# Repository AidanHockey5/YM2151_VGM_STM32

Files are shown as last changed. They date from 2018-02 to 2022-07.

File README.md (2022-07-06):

# This project has been superseded by...
https://github.com/AidanHockey5/YM2151_Arcade_Classic_2

# YM2151 Arcade Classic

http://www.aidanlawrence.com/ym2151-arcade-classic-adlib-mini/

See this project in action here: https://youtu.be/VlT8aX9DRZw

This project is a hardware Video Game Music (VGM) player that uses a genuine YM2151 FM synthesizer chip. 
This project is driven by an STM32 "Blue Pill" board, chosen for it's ample speed, I/O, and best of all, price!

Included in this repository is the source code for the project, all of the schematic files, a Bill of Materials, and a completed 
Ki-CAD printed circuitboard /w Gerber files. Feel free to produce your own board!

PCB

# Information about the main sound chips and VGM

The YM2151 was a popular sound synthesizer for classic arcade systems as well as a few higher-end home computers in the late 80's and early 90's.
This project synthesizes music from .VGM files in real time on genuine hardware. There is no emulation here.

VGM stands for Video Game Music, and it is a 44.1KHz logging format that stores real soundchip register information. My player will parse these files and send the data to the appropriate chips. You can learn more about the VGM file format here: http://www.smspower.org/Music/VGMFileFormat

http://www.smspower.org/uploads/Music/vgmspec170.txt?sid=58da937e68300c059412b536d4db2ca0

# SD Card Information
This project is built for full-sized SD cards, but you may use adapters to fit your desired card. You must format your SD card to Fat32 in order for this device to work correctly. Your SD card must only contain uncompressed .vgm files. VGZ FILES WILL NOT WORK! You may download .vgz files and use [7zip](http://www.7-zip.org/download.html) to extract the uncompressed file out of them. Vgm files on the SD card do not need to have the .vgm extension. As long as they contain valid, uncompressed vgm data, they will be read by the program regardless of their name.
You can find VGM files by Googling "myGameName VGM," or by checking out sites like http://vgmrips.net/packs/

# Control Over Serial
You can use a serial connection to control playback features. The commands are as follows:

Command | Result
------------ | -------------
\+ | Next Track
\- | Previous Track
\* | Random Track
\/ | Toggle Shuffle Mode
\. | Toggle Song Looping
r: | Request song

A song request is formatted as follows: ```r:mySongFile.vgm```
Once a song request is sent through the serial console, an attempt will be made to open that song file. The file must exist on the SD card, and spelling/capitalization must be correct.
Need an easy-to-use serial console? [I've made one here.](https://github.com/AidanHockey5/OpenArduinoSerialConsole)

# Schematic
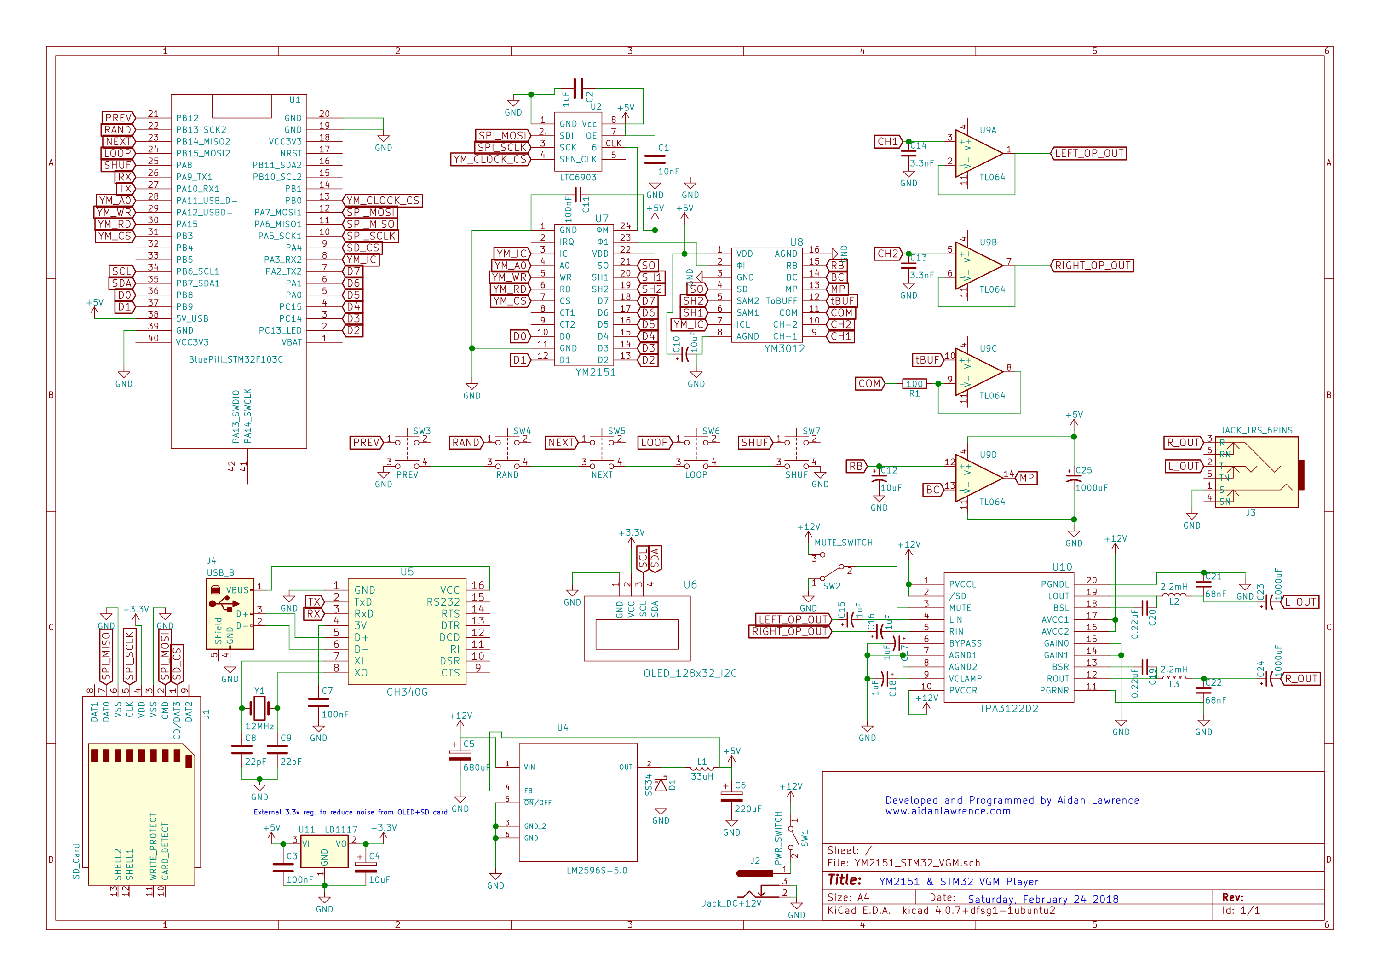
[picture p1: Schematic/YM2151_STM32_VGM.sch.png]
Schematic


[PDF](https://github.com/AidanHockey5/YM2151_VGM_STM32/raw/master/Schematic/YM2151_STM32_VGM.pdf)

[Bill Of Materials (BOM)](https://github.com/AidanHockey5/YM2151_VGM_STM32/tree/master/Schematic/BOM)

# KiCad
The schematic and PCB of this project was made in KiCad Version 4.0.7

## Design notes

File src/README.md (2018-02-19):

This project was a proof-of-concept to see if the STM32 could drive an FM synth chip.
There are no plans to support this project. For more detailed VGM players, see:
https://github.com/AidanHockey5/Teensy_3_5_VGM_Player_YM2612_SN76489
https://github.com/AidanHockey5/YM3812_VGM_Player

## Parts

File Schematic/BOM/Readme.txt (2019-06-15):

I've tried to keep as many components on Digikey as possible, but obviously, not everything will be on there.
That means that if you'd like a complete order of components, you must have all of the components from the DIGIKEY-BOM.csv file AND the EXTERNAL_BOM_ITEMS.txt list.

For items like resistors: Bog-standard 1/4 watt (the most common sizes you'd normally find in kits) will work, but I tried to track some down on Digikey any ways. 

For items listed on Aliexpress: Shop around and do your research. The links I provided should give you a great head start. Also check sources like eBay for similar goods.
LCSC can also provide parts at a significantly lower price than Digikey, but their selection is not as good. If you order a PCB from JLCPCB, you can ship components from LCSC combined for free.

You can use the Digikey BOM import tool to make this entire process much faster: https://www.digikey.com/BOM

Also, the 1000uF capacitors (C25, C24, C23) are actually have 2.5mm pin spacing, but Digikey only had 3.5mm spaced 8mm diameter caps. The fit isn't exactly perfect, but it's close enough to work.
If you can find 1000uF (16V or higher) capacitors that are 8mm in diameter and have 2.5mm pin spacing, I reccomend that you use those for a better fit.

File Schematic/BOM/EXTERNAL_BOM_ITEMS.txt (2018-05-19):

1x - J3 - AMP_OUT - PJ320E_3.5mm_Jack - https://www.aliexpress.com/wholesale?catId=0&initiative_id=SB_20180518120441&SearchText=PJ-320E
1x - U5 - CH340G - https://lcsc.com/product-detail/USB_CH340G_C14267.html 
1x - U1 - STM32 Bluepill Board - https://www.aliexpress.com/wholesale?catId=0&initiative_id=SB_20180518120532&SearchText=STM32F103C8T6
1x - U7 - YM2151 - https://www.aliexpress.com/wholesale?catId=0&initiative_id=SB_20180518182831&SearchText=YM2151
1x - U8 - YM3012 - https://www.aliexpress.com/w/wholesale-ym3012.html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
1x - U6 - 128x32 I2C OLED - https://www.aliexpress.com/wholesale?catId=0&initiative_id=SB_20180518182910&SearchText=128x32+I2C+OLED

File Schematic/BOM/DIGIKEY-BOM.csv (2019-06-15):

Manufacturer Part Number | Manufacturer | Digi-Key Part Number | Customer Reference | Reference Designator | Packaging | Part Status | Quantity | Unit Price | Extended Price | Quantity Available | Mfg Std Lead Time | Description | RoHS Status | Lead Free Status | REACH Status
ECS-120-20-4 | ECS Inc. | X227-ND |  |  | Bulk | Active | 1 | 0.69 | $0.69 | 1635 | 9 Weeks | CRYSTAL 12.0000MHZ 20PF T/H | RoHS non-compliant | Contains lead | REACH Unaffected
2041021-4 | TE Connectivity AMP Connectors | A101492CT-ND |  |  | Cut Tape (CT) | Active | 1 | 3.44 | $3.44 | 2777 | 11 Weeks | CONN SD CARD PUSH-PULL R/A SMD | RoHS Compliant | Lead free | Not Available
1825115-1 | TE Connectivity ALCOSWITCH Switches | 450-1598-ND |  |  | Bulk | Active | 2 | 0.98 | $1.96 | 3119 | 4 Weeks | SWITCH SLIDE SPDT 250MA 125V | RoHS Compliant | Lead free | Not Available
670688011 | Molex, LLC | WM12785-ND |  |  | Tube | Active | 1 | 2.06 | $2.06 | 1590 | 12 Weeks | USB B CONN WITH KINK BOARD LOCK | RoHS Compliant | Lead free | REACH Unaffected
16ZLH680MEFC10X12.5 | Rubycon | 1189-1150-ND |  |  | Bulk | Active | 1 | 0.43 | $0.43 | 6103 | 17 Weeks | CAP ALUM 680UF 20% 16V RADIAL | RoHS Compliant | Lead free | REACH Unaffected
LM2596S-5.0/NOPB | Texas Instruments | LM2596S-5.0/NOPB-ND |  |  | Tube | Active | 1 | 5.72 | $5.72 | 0 | 30 Weeks | IC REG BUCK 5V 3A TO263-5 | RoHS Compliant | Contains lead | REACH Unaffected
FG18X7R1H683KNT06 | TDK Corporation | 445-173278-1-ND |  |  | Cut Tape (CT) |  | 2 | 0.26 | $0.52 | 5414 | 40 Weeks | 0.068µF ±10% 50V Ceramic Capacitor X7R Radial | RoHS Compliant | Lead free | REACH Unaffected
PJ-002A | CUI Inc. | CP-002A-ND |  |  | Bag | Active | 1 | 0.6 | $0.60 | 113742 | Not Available | CONN PWR JACK 2X5.5MM SOLDER | RoHS Compliant | Lead free | Not Available
MBR0580S1-7 | Diodes Incorporated | MBR0580S1-7DICT-ND |  |  | Cut Tape (CT) | Active | 1 | 0.31 | $0.31 | 65469 | Not Available | DIODE SCHOTTKY 80V 500MA SOD123 | RoHS Compliant | Lead free | REACH Unaffected
K103K15X7RF5TL2 | Vishay BC Components | BC1078CT-ND |  |  | Cut Tape (CT) | Active | 1 | 0.19 | $0.19 | 9972 | 8 Weeks | CAP CER 10000PF 50V X7R RADIAL | RoHS Compliant | Lead free | Not Available
FG24X7R1H224KNT06 | TDK Corporation | 445-173377-1-ND |  |  | Cut Tape (CT) | Active | 2 | 0.29 | $0.58 | 4783 | 16 Weeks | CAP CER 0.22UF 50V X7R RADIAL | RoHS Compliant | Lead free | REACH Unaffected
LR1LJR10 | TE Connectivity Passive Product | A105964CT-ND |  |  | Cut Tape (CT) | Active | 1 | 0.39 | $0.39 | 12684 | 11 Weeks | RES 0.1 OHM 1/2W 5% AXIAL | RoHS Compliant | Lead free | Not Available
K104Z15Y5VF5TL2 | Vishay BC Components | BC1160CT-ND |  |  | Cut Tape (CT) | Active | 3 | 0.19 | $0.57 | 78547 | 8 Weeks | CAP CER 0.1UF 50V Y5V RADIAL | RoHS Compliant | Lead free | Not Available
UMA1C100MDD1TP | Nichicon | 493-10458-1-ND |  |  | Cut Tape (CT) | Active | 3 | 0.28 | $0.84 | 7221 | 21 Weeks | CAP ALUM 10UF 20% 16V RADIAL | RoHS Compliant | Lead free | REACH Unaffected
UMF1V010MDD1TP | Nichicon | 493-10230-1-ND |  |  | Cut Tape (CT) | Active | 4 | 0.45 | $1.80 | 2110 | 21 Weeks | CAP ALUM 1UF 20% 35V RADIAL | RoHS Compliant | Lead free | REACH Unaffected
FG28X7R1E105KRT06 | TDK Corporation | 445-173583-1-ND |  |  | Cut Tape (CT) | Active | 1 | 0.32 | $0.32 | 4648 | 16 Weeks | CAP CER 1UF 25V X7R RADIAL | RoHS Compliant | Lead free | REACH Unaffected
UVY1C221MED1TD | Nichicon | 493-12895-1-ND |  |  | Cut Tape (CT) | Active | 1 | 0.31 | $0.31 | 4437 | 18 Weeks | CAP ALUM 220UF 20% 16V RADIAL | RoHS Compliant | Lead free | REACH Unaffected
K220J15C0GF5TL2 | Vishay BC Components | BC1005CT-ND |  |  | Cut Tape (CT) | Active | 2 | 0.21 | $0.42 | 93566 | 8 Weeks | CAP CER 22PF 50V C0G/NP0 RADIAL | RoHS Compliant | Lead free | Not Available
K332K15X7RF5TL2 | Vishay BC Components | BC1075CT-ND |  |  | Cut Tape (CT) | Active | 2 | 0.2 | $0.40 | 42348 | 8 Weeks | CAP CER 3300PF 50V X7R RADIAL | RoHS Compliant | Lead free | Not Available
AIUR-16-330K | Abracon LLC | AIUR-16-330K-ND |  |  | Box | Active | 1 | 0.78 | $0.78 | 868 | 11 Weeks | FIXED IND 33UH 800MA 90 MOHM TH | RoHS Compliant | Lead free | REACH Unaffected
LTC6903CMS8#PBF | Linear Technology/Analog Devices | LTC6903CMS8#PBF-ND |  |  | Tube | Active | 1 | 4 | $4.00 | 311 | 8 Weeks | IC OSC SILICON PROG 8-MSOP | RoHS Compliant | Lead free | REACH Unaffected
B3F-1060 | Omron Electronics Inc-EMC Div | SW1177-ND |  |  | Bulk | Active | 5 | 0.34 | $1.70 | 2711 | 11 Weeks | SWITCH TACTILE SPST-NO 0.05A 24V | RoHS Compliant | Lead free | Not Available
TPA3122D2N | Texas Instruments | 296-23375-5-ND |  |  | Tube | Active | 1 | 3.31 | $3.31 | 421 | 6 Weeks | IC AMP AUDIO PWR 15W STER 20DIP | RoHS Compliant | Lead free | REACH Unaffected
A 20-LC-TT | Assmann WSW Components | AE9998-ND |  |  | Tube | Active | 1 | 0.29 | $0.29 | 44887 | 20 Weeks | CONN IC DIP SOCKET 20POS TIN | RoHS Compliant | Lead free | REACH Unaffected
A 24-LC-TT | Assmann WSW Components | AE10001-ND |  |  | Tube | Active | 1 | 0.35 | $0.35 | 6647 | 20 Weeks | CONN IC DIP SOCKET 24POS TIN | RoHS Compliant | Lead free | REACH Unaffected
A 16-LC-TT | Assmann WSW Components | AE9992-ND |  |  | Tube | Active | 1 | 0.25 | $0.25 | 44988 | 20 Weeks | CONN IC DIP SOCKET 16POS TIN | RoHS Compliant | Lead free | REACH Unaffected
A 14-LC-TT | Assmann WSW Components | AE9989-ND |  |  | Tube | Active | 1 | 0.22 | $0.44 | 121951 | 20 Weeks | CONN IC DIP SOCKET 14POS TIN | RoHS Compliant | Lead free | REACH Unaffected
TL064CN | Texas Instruments | 296-1773-5-ND |  |  | Tube | Active | 1 | 0.65 | $0.65 | 2461 | 6 Weeks | IC OPAMP JFET 1MHZ 14DIP | RoHS Compliant | Lead free | REACH Unaffected
RLB1014-222KL | Bourns Inc. | RLB1014-222KL-ND |  |  | Bag | Active | 2 | 0.43 | $0.86 | 1019 | 20 Weeks | FIXED IND 2.2MH 110MA 8.4 OHM TH | RoHS Compliant | Lead free | REACH Unaffected
UHV1C102MPD6 | Nichicon | 493-16434-ND |  |  | Bulk | Active | 3 | 0.65 | $1.95 | 677 | 20 Weeks | CAP ALUM 1000UF 20% 16V RADIAL | RoHS Compliant | Lead free | REACH Unaffected
LD1117S33CTR | STMicroelectronics | 497-1241-1-ND |  |  | Cut Tape (CT) | Active | 1 | 0.42 | $0.42 | 77479 | 10 Weeks | IC REG LINEAR 3.3V 800MA SOT223 | RoHS Compliant | Lead free | REACH Unaffected

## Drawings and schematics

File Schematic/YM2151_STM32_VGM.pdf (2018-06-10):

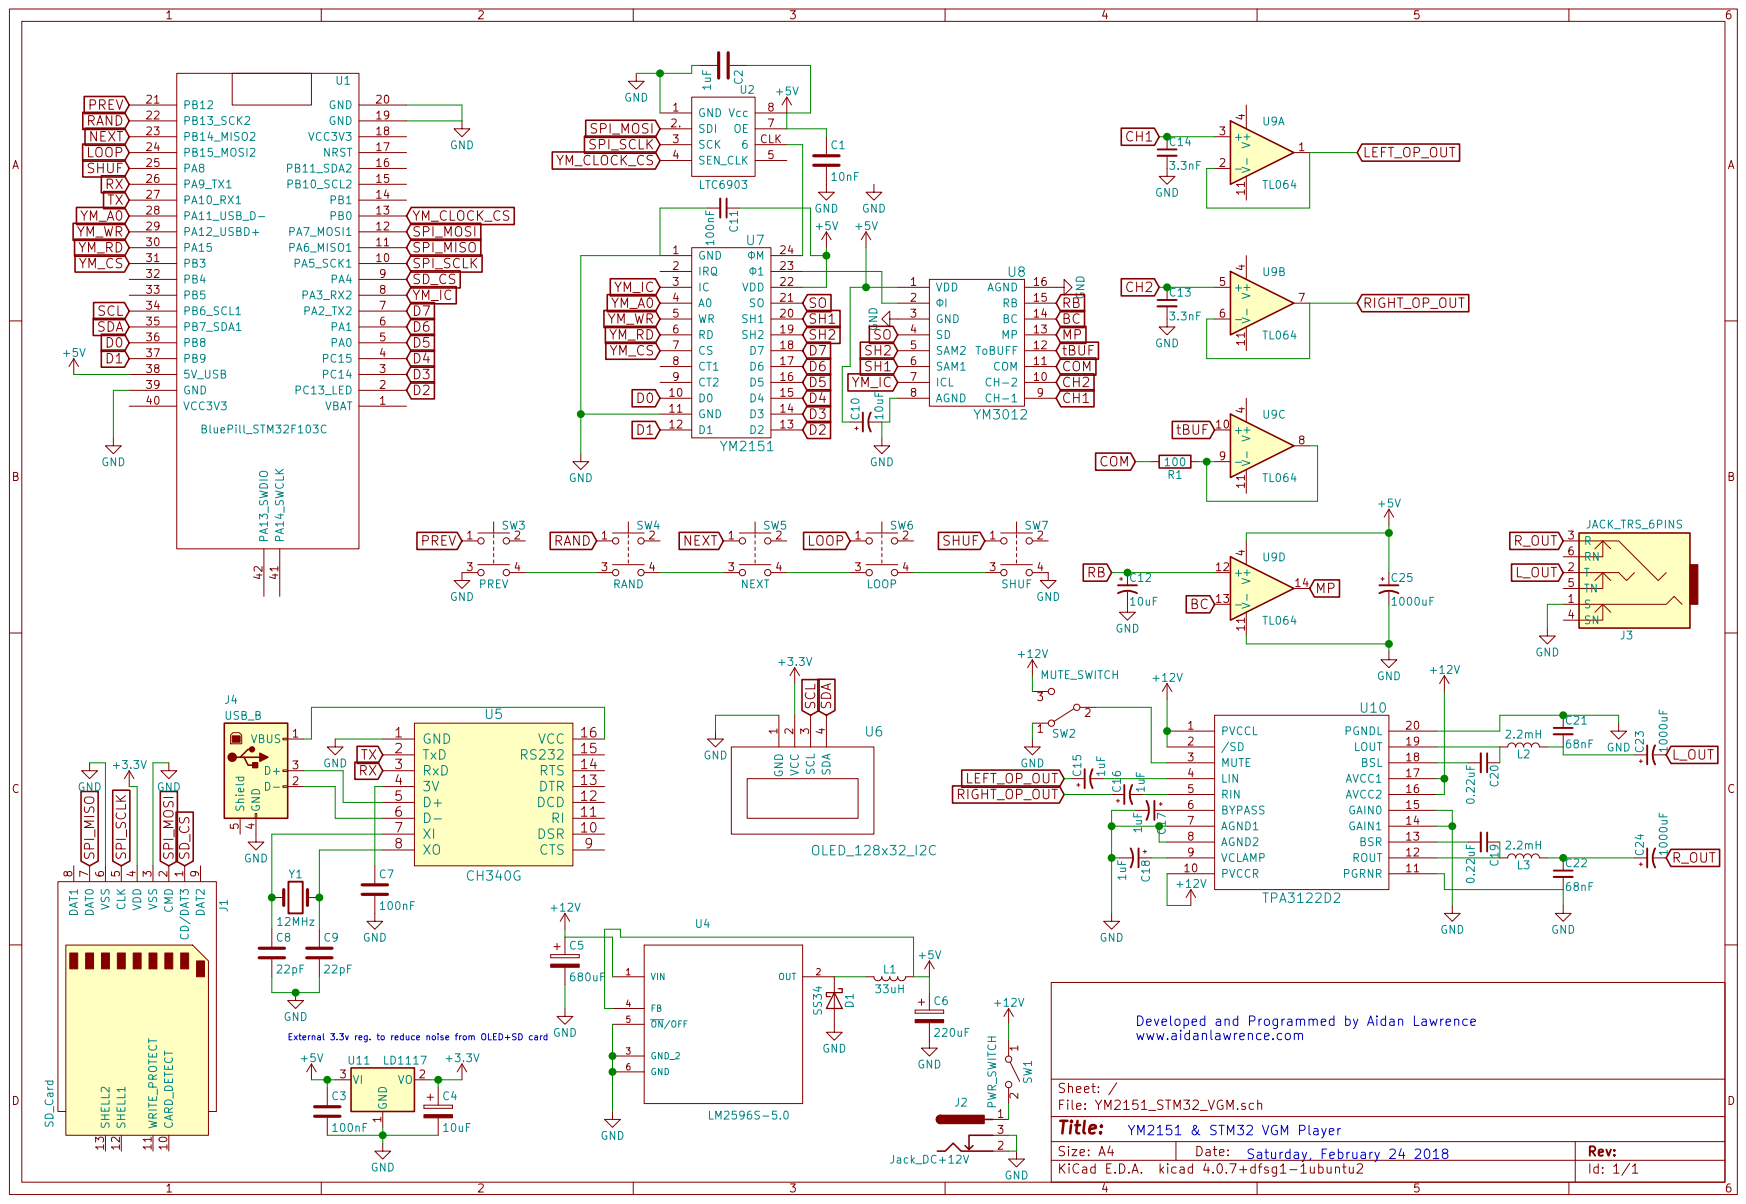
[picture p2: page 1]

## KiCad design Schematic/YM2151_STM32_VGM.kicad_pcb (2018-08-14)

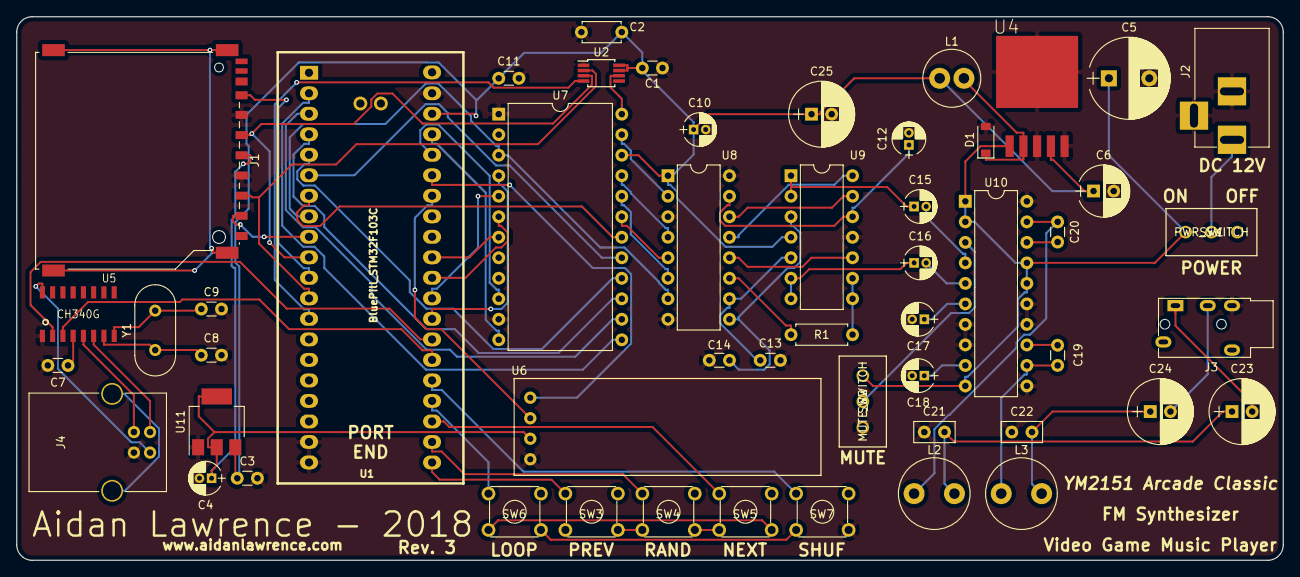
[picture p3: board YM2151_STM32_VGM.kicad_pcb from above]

Board: 2 copper layers, 156.8 x 67.3 mm, 52 parts (0 on the bottom side), 71 nets.

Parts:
C1: 10nF; C_Disc_D3.0mm_W1.6mm_P2.50mm
C2: 1uF; C_Disc_D4.7mm_W2.5mm_P5.00mm
C3, C7, C11: 100nF; C_Disc_D3.0mm_W1.6mm_P2.50mm
C4, C10, C12: 10uF; CP_Radial_D4.0mm_P1.50mm
C5: 680uF; CP_Radial_D10.0mm_P5.00mm
C6: 220uF; CP_Radial_D6.3mm_P2.50mm
C8, C9: 22pF; C_Disc_D3.0mm_W1.6mm_P2.50mm
C13, C14: 3.3nF; C_Disc_D3.0mm_W1.6mm_P2.50mm
C15, C16, C17, C18: 1uF; CP_Radial_D4.0mm_P1.50mm
C19, C20: 0.22uF; C_Disc_D3.0mm_W1.6mm_P2.50mm
C21, C22: 68nF; C_Disc_D5.0mm_W2.5mm_P2.50mm
C23, C24, C25: 1000uF; CP_Radial_D8.0mm_P2.50mm
D1: SS34; D_SOD-123
J1: SD_Card; SD_TE_2041021
J2: Jack_DC+12V; BARREL_JACK
J3: JACK_TRS_6PINS; PJ320E_3.5mm_Jack
J4: USB_B
L1: 33uH; L_Radial_D7.0mm_P3.00mm
L2, L3: 22uH; L_Radial_D8.7mm_P5.00mm_Fastron_07HCP
R1: 100; R_Axial_DIN0207_L6.3mm_D2.5mm_P7.62mm_Horizontal
SW1: PWR_SWITCH; 1825115-1
SW2: MUTE_SWITCH; 1825115-1
SW3: PREV; SW_TH_Tactile_Omron_B3F-10xx
SW4: RAND; SW_TH_Tactile_Omron_B3F-10xx
SW5: NEXT; SW_TH_Tactile_Omron_B3F-10xx
SW6: LOOP; SW_TH_Tactile_Omron_B3F-10xx
SW7: SHUF; SW_TH_Tactile_Omron_B3F-10xx
U1: BluePill_STM32F103C
U2: LTC6903; MSOP-8_3x3mm_Pitch0.65mm
U4: LM2596S-5.0; TO170P1435X465-6N
U5: CH340G; SOIC16
U6: OLED_128x32_I2C; 128x32_OLED_I2C_Module
U7: YM2151; DIP-24_W15.24mm
U8: YM3012; DIP-16_W7.62mm
U9: TL064; DIP-14_W7.62mm
U10: TPA3122D2; DIP-20_W7.62mm
U11: LD1117; SOT-223-3_TabPin2
Y1: 12MHz; Crystal_HC49-U_Vertical

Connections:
+3V3: C4.1, J1.4, U6.2, U11.2
+5V: C1.1, C2.1, C3.1, C6.1, C10.1, C11.1, C25.1, L1.1, U1.38, U2.7, U2.8, U4.4, U7.22, U8.1, U9.4, U11.3
+12V: C5.1, SW1.1, SW2.3, U4.1, U10.1, U10.2, U10.10, U10.16, U10.17
BC: U8.14, U9.13
CH1: C14.1, U8.9, U9.3
CH2: C13.1, U8.10, U9.5
COM: R1.2, U8.11
D0: U1.36, U7.10
D1: U1.37, U7.12
D2: U1.2, U7.13
D3: U1.3, U7.14
D4: U1.4, U7.15
D5: U1.5, U7.16
D6: U1.6, U7.17
D7: U1.7, U7.18
GND: C1.2, C2.2, C3.2, C4.2, C5.2, C6.2, C7.2, C8.2, C9.2, C10.2, C11.2, C12.2, C13.2, C14.2, C17.2, C18.2, C21.1, C22.2, C25.2, D1.2, J1.3, J1.6, J2.2, J2.3, J3.3, J4.4, SW2.1, SW3.3, SW7.4, U1.19, U1.20, U1.39, U2.1, U4.3, U4.5, U4.6, U5.1, U6.1, U7.1, U7.11, U8.3, U8.8, U8.16, U9.11, U10.7, U10.8, U10.11, U10.14, U10.15, U10.20, U11.1
LEFT_OP_OUT: C15.1, U9.1, U9.2
LOOP: SW6.1, U1.24
L_OUT: C23.2, J3.1
MP: U8.13, U9.14
NEXT: SW5.1, U1.23
unnamed: C7.1, U5.4
unnamed: C8.1, U5.7, Y1.1
unnamed: C9.1, U5.8, Y1.2
unnamed: C15.2, U10.4
unnamed: C16.2, U10.5
unnamed: C17.1, U10.6
unnamed: C18.1, U10.9
unnamed: C19.1, L3.1, U10.12
unnamed: C19.2, U10.13
unnamed: C20.1, L2.1, U10.19
unnamed: C20.2, U10.18
unnamed: C21.2, C23.1, L2.2
unnamed: C22.1, C24.1, L3.2
unnamed: D1.1, L1.2, U4.2
unnamed: J2.1, SW1.2
unnamed: J4.1, U5.16
unnamed: J4.2, U5.6
unnamed: J4.3, U5.5
unnamed: R1.1, U9.8, U9.9
unnamed: SW2.2, U10.3
unnamed: SW3.4, SW4.3
unnamed: SW4.4, SW5.3
unnamed: SW5.4, SW6.3
unnamed: SW6.4, SW7.3
unnamed: U2.6, U7.24
unnamed: U7.23, U8.2
PREV: SW3.1, U1.21
RAND: SW4.1, U1.22
RB: C12.1, U8.15, U9.12
RIGHT_OP_OUT: C16.1, U9.6, U9.7
RX: U1.26, U5.3
R_OUT: C24.2, J3.2
SCL: U1.34, U6.3
SDA: U1.35, U6.4
SD_CS: J1.1, U1.9
SH1: U7.20, U8.6
SH2: U7.19, U8.5
SHUF: SW7.1, U1.25
SO: U7.21, U8.4
SPI_MISO: J1.7, U1.11
SPI_MOSI: J1.2, U1.12, U2.2
SPI_SCLK: J1.5, U1.10, U2.3
TX: U1.27, U5.2
YM_A0: U1.28, U7.4
YM_CLOCK_CS: U1.13, U2.4
YM_CS: U1.31, U7.7
YM_IC: U1.8, U7.3, U8.7
YM_RD: U1.30, U7.6
YM_WR: U1.29, U7.5
tBUF: U8.12, U9.10

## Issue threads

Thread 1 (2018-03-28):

Error opening schematic in KiCad

SteveMoody73, 2018-03-28:
It looks like you're missing some library files. When opening the schematic in KiCad i get the following errors.

**The following libraries were not found:**

C:\Users\Aidan\Documents\KiCad_Custom_Libs\bluepill_breakouts
C:\Users\Aidan\Documents\Arduino\Teensy_3_5_VGM_Player_YM2612_SN76489\SchematicsAndInfo\Teensy_3_5_VGM_Player-cache
C:\Users\Aidan\Documents\KiCad_Custom_Libs\LM2596S-5.0
C:\Users\Aidan\Documents\KiCad_Custom_Libs\CH340G_D-SUN-V3.0-cache
C:\Users\Aidan\Documents\KiCad_Custom_Libs\VGM_Components_Library
C:\Users\Aidan\Documents\KiCad_Custom_Libs\TPA3122D2
C:\Users\Aidan\Documents\KiCad_Custom_Libs\DM3CS-SF
C:\Users\Aidan\Documents\KiCad_Custom_Libs\1825115Swit

AidanHockey5, 2018-03-31:
Sorry about that. I'm still getting over KiCAD's miserable library system. All footprints/symbols should now be locally stored within the project folder and referenced relative to the project's location.

Closed 2018-03-31.

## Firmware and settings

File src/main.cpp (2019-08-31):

#include <Arduino.h>
#include "YM2151.h"
#include "LTC6903.h"
#include <SPI.h>
#include <U8g2lib.h>
#include "SdFat.h"
#include "TrackStructs.h"
#include "ringbuffer.h"

//Debug variables
#define DEBUG false //Set this to true for a detailed printout of the header data & any errored command bytes
#define DEBUG_LED PA10
bool commandFailed = false;
uint8_t failedCmd = 0x00;

//Prototypes
void setup();
void loop();
void handleSerialIn();
void tick();
void removeMeta();
void prebufferLoop();
void injectPrebuffer();
void fillBuffer();
bool topUpBuffer(); 
void clearBuffers();
//void handleButtons();
void prepareChips();
void readGD3();
void setISR();
void drawOLEDTrackInfo();
bool startTrack(FileStrategy fileStrategy, String request = "");
bool vgmVerify();
uint8_t readBuffer();
uint16_t readBuffer16();
uint32_t readBuffer32();
uint32_t readSD32();
uint16_t parseVGM();

//Sound Chips
const int prev_btn = PB12;
const int rand_btn = PB13;
const int next_btn = PB14;
const int loop_btn = PB15;
const int shuf_btn = PA8;
int YM_Datapins[8] = {PB8, PB9, PC13, PC14, PC15, PA0, PA1, PA2};
const int YM_CS = PB3;
const int YM_RD = PA15;
const int YM_WR = PA12;
const int YM_A0 = PA11;
const int YM_IC = PA3; 
const int YM_IRQ = NULL;
YM2151 opm(YM_Datapins, YM_CS, YM_RD, YM_WR, YM_A0, YM_IRQ, YM_IC);

//Clock
LTC6903 ltc(PB0);

//SD & File Streaming
SdFat SD;
File file;
#define MAX_FILE_NAME_SIZE 128
char fileName[MAX_FILE_NAME_SIZE];
uint32_t numberOfFiles = 0;
uint32_t currentFileNumber = 0;

//Buffers
#define CMD_BUFFER_SIZE 8192
#define LOOP_PREBUF_SIZE 512
typedef ringbuffer_t<uint8_t, CMD_BUFFER_SIZE, uint8_t> RingBuffer;
static RingBuffer cmdBuffer;
uint8_t loopPreBuffer[LOOP_PREBUF_SIZE];

//Counters
uint32_t bufferPos = 0;
uint32_t cmdPos = 0;
uint16_t waitSamples = 0;

//VGM Variables
uint16_t loopCount = 0;
uint8_t maxLoops = 3;
bool fetching = false;
volatile bool ready = false;
PlayMode playMode = SHUFFLE;

//OLED
U8G2_SSD1306_128X32_UNIVISION_F_HW_I2C u8g2(U8G2_R0);

void setup()
{
  ltc.SetFrequency(3579545); 
  u8g2.begin();
  u8g2.setFont(u8g2_font_fub11_tf);
  u8g2.clearBuffer();
  u8g2.drawStr(0,16,"Aidan Lawrence");
  u8g2.drawStr(0,32,"YM2151, 2018");
  u8g2.sendBuffer();
  delay(500);
  pinMode(prev_btn, INPUT_PULLUP);
  pinMode(rand_btn, INPUT_PULLUP);
  pinMode(next_btn, INPUT_PULLUP);
  pinMode(loop_btn, INPUT_PULLUP);
  pinMode(shuf_btn, INPUT_PULLUP);

  //COM
  Serial.begin(9600);

  //SD
  if(!SD.begin(PA4, SD_SCK_HZ(F_CPU/2)))
  {
    u8g2.clearBuffer();
    u8g2.drawStr(0,16,"SD Mount");
    u8g2.drawStr(0,32,"failed!");
    u8g2.sendBuffer();
    while(true){Serial.println("SD MOUNT FAILED"); delay(1000);}
  }

  //Prepare files
  removeMeta();

  File countFile;
  while ( countFile.openNext( SD.vwd(), O_READ ))
  {
    countFile.close();
    numberOfFiles++;
  }
  countFile.close();
  SD.vwd()->rewind();

  //44.1KHz tick
  setISR();

  //Begin
  startTrack(FIRST_START);
  vgmVerify();
  prepareChips();
}

void setISR()
{
  Timer4.pause();
  Timer4.setPrescaleFactor(1);
  Timer4.setOverflow(1633);
  Timer4.setChannel1Mode(TIMER_OUTPUT_COMPARE);
  Timer4.attachCompare1Interrupt(tick);
  Timer4.refresh();
  Timer4.resume();  
}

void prepareChips()
{
  opm.Reset();
}

void drawOLEDTrackInfo()
{
  u8g2.setFont(u8g2_font_helvR08_tf);
  u8g2.clearBuffer();
  char *cstr = &gd3.enTrackName[0u];
  u8g2.drawStr(0,9, cstr);
  cstr = &gd3.enGameName[0u];
  u8g2.drawStr(0,22, cstr);

  u8g2.setFont(u8g2_font_micro_tr);
  if(playMode == LOOP)
    u8g2.drawStr(0,32, "LOOP");
  else if(playMode == SHUFFLE)
    u8g2.drawStr(0,32, "SHUFFLE");
  else
    u8g2.drawStr(0,32, "IN ORDER");
  u8g2.sendBuffer();
}

//Mount file and prepare for playback. Returns true if file is found.
bool startTrack(FileStrategy fileStrategy, String request)
{
  ready = false;
  File nextFile;
  memset(fileName, 0x00, MAX_FILE_NAME_SIZE);

  switch(fileStrategy)
  {
    case FIRST_START:
    {
      nextFile.openNext(SD.vwd(), O_READ);
      nextFile.getName(fileName, MAX_FILE_NAME_SIZE);
      nextFile.close();
      currentFileNumber = 0;
    }
    break;
    case NEXT:
    {
      if(currentFileNumber+1 >= numberOfFiles)
      {
          SD.vwd()->rewind();
          currentFileNumber = 0;
      }
      else
          currentFileNumber++;
      nextFile.openNext(SD.vwd(), O_READ);
      nextFile.getName(fileName, MAX_FILE_NAME_SIZE);
      nextFile.close();
    }
    break;
    case PREV:
    {
      if(currentFileNumber != 0)
      {
        currentFileNumber--;
        SD.vwd()->rewind();
        for(uint32_t i = 0; i<=currentFileNumber; i++)
        {
          nextFile.close();
          nextFile.openNext(SD.vwd(), O_READ);
        }
        nextFile.getName(fileName, MAX_FILE_NAME_SIZE);
        nextFile.close();
      }
      else
      {
        currentFileNumber = numberOfFiles-1;
        SD.vwd()->rewind();
        for(uint32_t i = 0; i<=currentFileNumber; i++)
        {
          nextFile.close();
          nextFile.openNext(SD.vwd(), O_READ);
        }
        nextFile.getName(fileName, MAX_FILE_NAME_SIZE);
        nextFile.close();
      }
    }
    break;
    case RND:
    {
      randomSeed(micros());
      uint32_t randomFile = currentFileNumber;
      if(numberOfFiles > 1)
      {
        while(randomFile == currentFileNumber)
          randomFile = random(numberOfFiles-1);
      }
      currentFileNumber = randomFile;
      SD.vwd()->rewind();
      nextFile.openNext(SD.vwd(), O_READ);
      {
        for(uint32_t i = 0; i<randomFile; i++)
        {
          nextFile.close();
          nextFile.openNext(SD.vwd(), O_READ);
        }
      }
      nextFile.getName(fileName, MAX_FILE_NAME_SIZE);
      nextFile.close();
    }
    break;
    case REQUEST:
    {
      SD.vwd()->rewind();
      bool fileFound = false;
      Serial.print("REQUEST: ");Serial.println(request);
      for(uint32_t i = 0; i<numberOfFiles; i++)
      {
        nextFile.close();
        nextFile.openNext(SD.vwd(), O_READ);
        nextFile.getName(fileName, MAX_FILE_NAME_SIZE);
        String tmpFN = String(fileName);
        tmpFN.trim();
        request.trim();
        if(tmpFN == request)
        {
          currentFileNumber = i;
          fileFound = true;
          break;
        }
      }
      nextFile.close();
      if(fileFound)
      {
        Serial.println("File found!");
      }
      else
      {
        Serial.println("ERROR: File not found! Continuing with current song.");
        ready = true;
        return false;
      }
    }
    break;
  }

  cmdPos = 0;
  bufferPos = 0;
  waitSamples = 0;
  loopCount = 0;

  if(file.isOpen())
    file.close();
  file = SD.open(fileName, FILE_READ);
  if(!file)
    Serial.println("Failed to read file");

  clearBuffers();
  memset(&loopPreBuffer, 0, LOOP_PREBUF_SIZE);
  header.Reset();
  fillBuffer();

  //VGM Header
  header.indent = readBuffer32();
  header.EoF = readBuffer32(); 
  header.version = readBuffer32(); 
  header.sn76489Clock = readBuffer32(); 
  header.ym2413Clock = readBuffer32();
  header.gd3Offset = readBuffer32();
  header.totalSamples = readBuffer32(); 
  header.loopOffset = readBuffer32(); 
  header.loopNumSamples = readBuffer32(); 
  header.rate = readBuffer32(); 
  header.snX = readBuffer32(); 
  header.ym2612Clock = readBuffer32(); 
  header.ym2151Clock = readBuffer32(); 
  header.vgmDataOffset = readBuffer32(); 
  header.segaPCMClock = readBuffer32(); 
  header.spcmInterface = readBuffer32(); 
  header.rf5C68clock = readBuffer32();
  header.ym2203clock = readBuffer32();
  header.ym2608clock = readBuffer32();
  header.ym2610clock = readBuffer32();
  header.ym3812clock = readBuffer32();
  header.ym3526clock = readBuffer32();
  header.y8950clock = readBuffer32();
  header.ymf262clock = readBuffer32();
  header.ymf271clock = readBuffer32();
  header.ymz280Bclock = readBuffer32();
  header.rf5C164clock = readBuffer32();
  header.pwmclock = readBuffer32();
  header.ay8910clock = readBuffer32();
  header.ayclockflags = readBuffer32();
  header.vmlblm = readBuffer32();
  if(header.version > 0x151)
  {
    header.gbdgmclock = readBuffer32();
    header.nesapuclock = readBuffer32();
    header.multipcmclock = readBuffer32();
    header.upd7759clock = readBuffer32();
    header.okim6258clock = readBuffer32();
    header.ofkfcf = readBuffer32();
    header.okim6295clock = readBuffer32();
    header.k051649clock = readBuffer32();
    header.k054539clock = readBuffer32();
    header.huc6280clock = readBuffer32();
    header.c140clock = readBuffer32();
    header.k053260clock = readBuffer32();
    header.pokeyclock = readBuffer32();
    header.qsoundclock = readBuffer32();
    header.scspclock = readBuffer32();
    header.extrahdrofs = readBuffer32();
    header.wonderswanclock = readBuffer32();
    header.vsuClock = readBuffer32();
    header.saa1099clock = readBuffer32();
  }

  #if DEBUG
  Serial.print("Indent: 0x"); Serial.println(header.indent, HEX);
  Serial.print("EoF: 0x"); Serial.println(header.EoF, HEX);
  Serial.print("Version: 0x"); Serial.println(header.version, HEX);
  Serial.print("SN Clock: "); Serial.println(header.sn76489Clock);
  Serial.print("YM2413 Clock: "); Serial.println(header.ym2413Clock);
  Serial.print("GD3 Offset: 0x"); Serial.println(header.gd3Offset, HEX);
  Serial.print("Total Samples: "); Serial.println(header.totalSamples);
  Serial.print("Loop Offset: 0x"); Serial.println(header.loopOffset, HEX);
  Serial.print("Loop # Samples: "); Serial.println(header.loopNumSamples);
  Serial.print("Rate: "); Serial.println(header.rate);
  Serial.print("SN etc.: 0x"); Serial.println(header.snX, HEX);
  Serial.print("YM2612 Clock: "); Serial.println(header.ym2612Clock);
  Serial.print("YM2151 Clock: "); Serial.println(header.ym2151Clock);
  Serial.print("VGM data Offset: 0x"); Serial.println(header.vgmDataOffset, HEX);
  Serial.print("SPCM Interface: 0x"); Serial.println(header.spcmInterface, HEX);
  Serial.println("...");
  Serial.print("YM3812 Clock: 0x"); Serial.println(header.ym3812clock, HEX);
  Serial.print("YMF262clock Clock: 0x"); Serial.println(header.ymf262clock, HEX);
  Serial.print("SAA1099 Clock: 0x"); Serial.println(header.saa1099clock, HEX);
  #endif

  //Jump to VGM data start and compute loop location
  if(header.vgmDataOffset == 0x0C)
    header.vgmDataOffset = 0x40;
  else
    header.vgmDataOffset += 0x34;
  
  if(header.vgmDataOffset != 0x40)
  {
    for(uint32_t i = 0x40; i<header.vgmDataOffset; i++)
      readBuffer();
  }
  if(header.loopOffset == 0x00)
  {
    header.loopOffset = header.vgmDataOffset;
  }
  else
    header.loopOffset += 0x1C;

  prebufferLoop();
  #if DEBUG
  //Dump the contents of the prebuffer
  for(int i = 0; i<LOOP_PREBUF_SIZE; i++)
  {
    if(i % 32 == 0)
      Serial.println();
    Serial.print("0x"); Serial.print(loopPreBuffer[i], HEX); Serial.print(", ");
  }
  #endif
  return true;
}

bool vgmVerify()
{
  if(header.indent != 0x206D6756) //VGM. Indent check
  {
    startTrack(NEXT);
    return false;
  }
  ltc.SetFrequency(header.ym2151Clock);
  Serial.println("VGM OK!");
  readGD3();
  Serial.println(gd3.enGameName);
  Serial.println(gd3.enTrackName);
  Serial.println(gd3.enSystemName);
  Serial.println(gd3.releaseDate);
  Serial.print("Version: "); Serial.println(header.version, HEX);
  drawOLEDTrackInfo();
  ready = true;
  return true;
}

void readGD3()
{
  uint32_t prevLocation = file.curPosition();
  uint32_t tag = 0;
  gd3.Reset();
  file.seek(0);
  file.seek(header.gd3Offset+0x14);
  for(int i = 0; i<4; i++) {tag += uint32_t(file.read());} //Get GD3 tag bytes and add them up for an easy comparison.
  if(tag != 0xFE) //GD3 tag bytes do not sum up to the constant. No valid GD3 data detected. 
  {Serial.print("INVALID GD3 SUM:"); Serial.println(tag); file.seekSet(prevLocation); return;}
  for(int i = 0; i<4; i++) {file.read();} //Skip version info
  uint8_t v[4];
  file.readBytes(v,4);
  gd3.size = uint32_t(v[0] + (v[1] << 8) + (v[2] << 16) + (v[3] << 24));
  char a, b;
  uint8_t itemIndex = 0;
  for(uint32_t i = 0; i<gd3.size; i++)
  {
    a = file.read();
    b = file.read();
    if(a+b == 0) //Double 0 detected
    {
      itemIndex++;
      continue;
    }
    switch(itemIndex)
    {
      case 0:
      gd3.enTrackName += a;
      break;
      case 1:
      //JP TRACK NAME
      break;
      case 2:
      gd3.enGameName += a;
      break;
      case 3:
      //JP GAME NAME
      break;
      case 4:
      gd3.enSystemName += a;
      break;
      case 5:
      //JP SYSTEM NAME
      break;
      case 6:
      gd3.enAuthor += a;
      break;
      case 7:
      //JP AUTHOR
      break;
      case 8:
      gd3.releaseDate += a;
      break;
      default:
      //IGNORE CONVERTER NAME + NOTES
      break;
    }
  }
  file.seekSet(prevLocation);
}

void removeMeta() //Remove useless meta files
{
  File tmpFile;
  while ( tmpFile.openNext( SD.vwd(), O_READ ))
  {
    memset(fileName, 0x00, MAX_FILE_NAME_SIZE);
    tmpFile.getName(fileName, MAX_FILE_NAME_SIZE);
    if(fileName[0]=='.')
    {
      if(!SD.remove(fileName))
      if(!tmpFile.rmRfStar())
      {
        Serial.print("FAILED TO DELETE META FILE"); Serial.println(fileName);
      }
    }
    if(String(fileName) == "System Volume Information")
    {
      if(!tmpFile.rmRfStar())
        Serial.println("FAILED TO REMOVE SVI");
    }
    tmpFile.close();
  }
  tmpFile.close();
  SD.vwd()->rewind();
}

//Keep a small cache of commands right at the loop point to prevent excessive SD seeking lag
void prebufferLoop() 
{
  uint32_t prevPos = file.curPosition();
  file.seekSet(header.loopOffset);
  file.readBytes(loopPreBuffer, LOOP_PREBUF_SIZE);
  file.seekSet(prevPos);
  #if DEBUG
  Serial.print("FIRST LOOP BYTE: "); Serial.println(loopPreBuffer[0], HEX);
  #endif
}

//On loop, inject the small prebuffer back into the main ring buffer
void injectPrebuffer()
{
  for(int i = 0; i<LOOP_PREBUF_SIZE; i++)
    cmdBuffer.push_back(loopPreBuffer[i]);
  file.seekSet(header.loopOffset+LOOP_PREBUF_SIZE);
  cmdPos = LOOP_PREBUF_SIZE-1;
  #if DEBUG
  Serial.println(file.curPosition());
  #endif
}

//Completely fill command buffer
void fillBuffer()
{
  while(!topUpBuffer()){};
}

//Add to buffer from SD card. Returns true when buffer is full
bool topUpBuffer() 
{
  if(cmdBuffer.full())
    return true;
  if(cmdBuffer.available() >= file.size()) 
     return true;
  fetching = true;
  cmdBuffer.push_back_nc(file.read());
  bufferPos = 0;
  fetching = false;
  return false;
}

void clearBuffers()
{
  bufferPos = 0;
  cmdBuffer.clear();
}

uint8_t readBuffer()
{
  if(cmdBuffer.empty()) //Buffer exauhsted prematurely. Force replenish
  {
    topUpBuffer();
  }
  bufferPos++;
  cmdPos++;
  return cmdBuffer.pop_front_nc();
}

uint16_t readBuffer16()
{
  uint16_t d;
  byte v0 = readBuffer();
  byte v1 = readBuffer();
  d = uint16_t(v0 + (v1 << 8));
  bufferPos+=2;
  cmdPos+=2;
  return d;
}

uint32_t readBuffer32()
{
  uint32_t d;
  byte v0 = readBuffer();
  byte v1 = readBuffer();
  byte v2 = readBuffer();
  byte v3 = readBuffer();
  d = uint32_t(v0 + (v1 << 8) + (v2 << 16) + (v3 << 24));
  bufferPos+=4;
  cmdPos+=4;
  return d;
}

//Read 32 bits right off of the SD card.
uint32_t readSD32()
{
  uint32_t d;
  byte v[4];
  file.readBytes(v, 4);
  d = uint32_t(v[0] + (v[1] << 8) + (v[2] << 16) + (v[3] << 24));
  return d;
}

//Count at 44.1KHz
void tick()
{
  if(!ready || cmdBuffer.empty())
    return;
  if(waitSamples > 0)
    waitSamples--;
}

//Execute next VGM command set. Return back wait time in samples
uint16_t parseVGM() 
{
  uint8_t cmd = readBuffer();
  switch(cmd)
  {
    case 0x54:
    {
      uint8_t a = readBuffer();
      uint8_t d = readBuffer();
      opm.SendDataPins(a, d);
      break;
    }
    case 0x61:
    return readBuffer16();
    case 0x62:
    return 735;
    case 0x63:
    return 882;
    case 0x67: //Ignore PCM data blocks
    {
        readBuffer(); //0x66
        readBuffer(); //Datatype
        uint32_t pcmSize = readBuffer32(); //Payload size;
        for(int i=0; i<pcmSize; i++)
          readBuffer();
        break;
    }
    case 0xB5: //Ignore common secondary PCM chips
    case 0xB6:
    case 0xB7:
    case 0xB8:
    case 0xB9:
    case 0xBA:
    case 0xBB:
    case 0xBC:
    case 0xBD:
    case 0xBE:
    case 0xBF:
    readBuffer16();
    break;
    case 0xC0: //Ignore SegaPCM:
    case 0xC1:
    case 0xC2:
    case 0xC3:
    readBuffer();readBuffer();readBuffer();
    break;
    case 0x70:
    case 0x71:
    case 0x72:
    case 0x73:
    case 0x74:
    case 0x75:
    case 0x76:
    case 0x77:
    case 0x78:
    case 0x79:
    case 0x7A:
    case 0x7B:
    case 0x7C:
    case 0x7D:
    case 0x7E:
    case 0x7F:
    {
      return (cmd & 0x0F)+1;
    }
    case 0x66:
    {
    ready = false;
    clearBuffers();
    cmdPos = 0;
    injectPrebuffer();
    loopCount++;
    ready = true;
    }
    return 0;
    default:
    commandFailed = true;
    failedCmd = cmd;
    return 0;
  }
  return 0;
}

//Poll the serial port
void handleSerialIn()
{
  bool newTrack = false;
  while(Serial.available())
  {
    char serialCmd = Serial.read();
    switch(serialCmd)
    {
      case '+':
        newTrack = startTrack(NEXT);
      break;
      case '-':
        newTrack = startTrack(PREV);
      break;
      case '*':
        newTrack = startTrack(RND);
      break;
      case '/':
        playMode = SHUFFLE;
        drawOLEDTrackInfo();
      break;
      case '.':
        playMode = LOOP;
        drawOLEDTrackInfo();
      break;
      case '?':
        Serial.println(gd3.enGameName);
        Serial.println(gd3.enTrackName);
        Serial.println(gd3.enSystemName);
        Serial.println(gd3.releaseDate);
        Serial.print("Version: "); Serial.println(header.version, HEX);
      break;
      case '!':

      break;
      case 'r':
      {
        String req = Serial.readString();
        req.remove(0, 1); //Remove colon character
        newTrack = startTrack(REQUEST, req);
      }
      break;
      default:
        continue;
    }
  }
  if(newTrack)
  {
    vgmVerify();
    prepareChips();
  }
}

//Check for button input
bool buttonLock = false;
void handleButtons()
{
  bool newTrack = false;
  uint32_t count = 0;
  
  if(!digitalRead(next_btn))
    newTrack = startTrack(NEXT);
  if(!digitalRead(prev_btn))
    newTrack = startTrack(PREV);
  if(!digitalRead(rand_btn))
    newTrack = startTrack(RND);
  if(!digitalRead(shuf_btn) && !buttonLock)
  {
    playMode == SHUFFLE ? playMode = IN_ORDER : playMode = SHUFFLE;
    drawOLEDTrackInfo();
    buttonLock = true;
    delay(50);
  }
  if(!digitalRead(loop_btn) && !buttonLock)
  {
    playMode == LOOP ? playMode = IN_ORDER : playMode = LOOP;
    drawOLEDTrackInfo();
    buttonLock = true;
    delay(50);
  }

  if(buttonLock)
  {  
    if(digitalRead(loop_btn) && digitalRead(shuf_btn))
      buttonLock = false;
  }
  if(newTrack)
  {
    vgmVerify();
    prepareChips();
    delay(100);
  }
}

void loop()
{    
  topUpBuffer();
  if(waitSamples == 0)
  {
    waitSamples += parseVGM();
    return;
  }
  if(loopCount >= maxLoops && playMode != LOOP)
  {
    bool newTrack = false;
    if(playMode == SHUFFLE)
      newTrack = startTrack(RND);
    if(playMode == IN_ORDER)
      newTrack = startTrack(NEXT);
    if(newTrack)
    {
      vgmVerify();
      prepareChips();
    }
  }
  if(Serial.available() > 0)
    handleSerialIn();
  handleButtons();
  #if DEBUG
  if(commandFailed)
  {
    commandFailed = false;
    Serial.print("CMD ERROR: "); Serial.println(failedCmd, HEX);
  }
  #endif
}

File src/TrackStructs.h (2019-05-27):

#ifndef TRACKSTRUCTS_H_
#define TRACKSTRUCTS_H_
#include <stdint.h>
struct VGMHeader
{
    uint32_t indent;
    uint32_t EoF;
    uint32_t version;
    uint32_t sn76489Clock;
    uint32_t ym2413Clock;
    uint32_t gd3Offset;
    uint32_t totalSamples;
    uint32_t loopOffset;
    uint32_t loopNumSamples;
    uint32_t rate;
    uint32_t snX;
    uint32_t ym2612Clock;
    uint32_t ym2151Clock;
    uint32_t vgmDataOffset;
    uint32_t segaPCMClock;
    uint32_t spcmInterface;
    uint32_t rf5C68clock;
    uint32_t ym2203clock;
    uint32_t ym2608clock;
    uint32_t ym2610clock;
    uint32_t ym3812clock;
    uint32_t ym3526clock;
    uint32_t y8950clock;
    uint32_t ymf262clock;
    uint32_t ymf271clock;
    uint32_t ymz280Bclock;
    uint32_t rf5C164clock;
    uint32_t pwmclock;
    uint32_t ay8910clock;
    uint32_t ayclockflags;
    uint32_t vmlblm;
    uint32_t gbdgmclock;
    uint32_t nesapuclock;
    uint32_t multipcmclock;
    uint32_t upd7759clock;
    uint32_t okim6258clock;
    uint32_t ofkfcf;
    uint32_t okim6295clock;
    uint32_t k051649clock;
    uint32_t k054539clock;
    uint32_t huc6280clock;
    uint32_t c140clock;
    uint32_t k053260clock;
    uint32_t pokeyclock;
    uint32_t qsoundclock;
    uint32_t scspclock;
    uint32_t extrahdrofs;
    uint32_t wonderswanclock;
    uint32_t vsuClock;
    uint32_t saa1099clock;

    void Reset()
    {
        indent = 0;
        EoF = 0;
        version = 0;
        sn76489Clock = 0;
        ym2413Clock = 0;
        gd3Offset = 0;
        totalSamples = 0;
        loopOffset = 0;
        loopNumSamples = 0;
        rate = 0;
        snX = 0;
        ym2612Clock = 0;
        ym2151Clock = 0;
        vgmDataOffset = 0;
        segaPCMClock = 0;
        spcmInterface = 0;
        rf5C68clock = 0;
        ym2203clock = 0;
        ym2608clock = 0;
        ym2610clock = 0;
        ym3812clock = 0;
        ym3526clock = 0;
        y8950clock = 0;
        ymf262clock = 0;
        ymf271clock = 0;
        ymz280Bclock = 0;
        rf5C164clock = 0;
        pwmclock = 0;
        ay8910clock = 0;
        ayclockflags = 0;
        vmlblm = 0;
        gbdgmclock = 0;
        nesapuclock = 0;
        multipcmclock = 0;
        upd7759clock = 0;
        okim6258clock = 0;
        ofkfcf = 0;
        okim6295clock = 0;
        k051649clock = 0;
        k054539clock = 0;
        huc6280clock = 0;
        c140clock = 0;
        k053260clock = 0;
        pokeyclock = 0;
        qsoundclock = 0;
        scspclock = 0;
        extrahdrofs = 0;
        wonderswanclock = 0;
        vsuClock = 0;
        saa1099clock = 0;
    }
};

struct GD3
{
    uint32_t size;
    String enTrackName;
    String enGameName;
    String enSystemName;
    String enAuthor;
    String releaseDate;
    void Reset()
    {
        size = 0;
        enTrackName = "";
        enGameName = "";
        enSystemName = "";
        enAuthor = "";
        releaseDate = "";
    }
};

enum FileStrategy {FIRST_START, NEXT, PREV, RND, REQUEST};
enum PlayMode {LOOP, PAUSE, SHUFFLE, IN_ORDER};
static VGMHeader header;
static GD3 gd3;
#endif

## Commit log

2018-02-19 Full VGM player for YM2151 with STM32. LTC6903 now supports dynamic clocking.
2018-02-25 Added OLED. Began schematic. Project is feature-complete
    [YM2151_STM32_VGM.kicad_pcb, YM2151_STM32_VGM.sch]
2018-02-25 Schematic complete
    [YM2151_STM32_VGM.sch]
2018-02-25 In progress of appending footprints
    [YM2151_STM32_VGM.sch]
2018-02-25 Footprint selection finalized
    [YM2151_STM32_VGM.sch]
2018-02-26 Finalizing PCB
    [YM2151_STM32_VGM.dsn, YM2151_STM32_VGM.sch]
2018-02-26 PCB complete
    [YM2151_STM32_VGM-B.Cu.gbr, YM2151_STM32_VGM-B.Mask.gbr, YM2151_STM32_VGM-B.Paste.gbr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]
2018-02-26 Corrected PCB - unconnected GND on LTC6903
    [YM2151_STM32_VGM-B.Cu.gbr, YM2151_STM32_VGM-B.Mask.gbr, YM2151_STM32_VGM-B.Paste.gbr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]
2018-03-03 Corrected SD card on schematic and board. Added button control
    [YM2151_STM32_VGM-B.Cu.gbr, YM2151_STM32_VGM-B.Mask.gbr, YM2151_STM32_VGM-B.Paste.gbr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]
2018-03-03 Fixed no-clock on startup, added switch debounce
    [main.cpp]
2018-03-03 Added Bill of Materials
    [BOM.xlsx]
2018-03-13 Correct clock startup sequence to always start on a safe frequency.
    [main.cpp]
2018-03-15 Now skips data blocks reserved for PCM chips
    [main.cpp]
2018-03-16 Corrected YM2151 reset on startup that would cause garbled sound on first track.
    [main.cpp]
2018-03-31 Added footprint archive
2018-05-19 Added improved BOM
    [BOM.xlsx, DIGIKEY-BOM.csv]
2018-05-19 Update Readme and BOM files
2018-05-19 Updated BOM component references
2018-06-10 Corrected schematic. L2, L3 inductors 22uH->2.2mH
2018-06-10 Correct schematic and BOM. L2 L3 22uH->2.2mH
    [DIGIKEY-BOM.csv]
2018-07-09 Fixed random song crash when only one file is present and fixed occasional start-up clocking failure
    [main.cpp]
2018-07-09 Deactivated INVERTED CLOCK pin on LTC6903
2018-08-14 Repaired headphone jack pinout on PCB.
    [YM2151_STM32_VGM-B.Cu.gbr, YM2151_STM32_VGM-B.Mask.gbr, YM2151_STM32_VGM-B.Paste.gbr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]
2018-08-25 Changed private BOM link public cart link
2019-05-27 New VGM driver backported
2019-06-15 BOM correction
    [DIGIKEY-BOM.csv]

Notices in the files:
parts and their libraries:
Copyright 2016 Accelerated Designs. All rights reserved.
